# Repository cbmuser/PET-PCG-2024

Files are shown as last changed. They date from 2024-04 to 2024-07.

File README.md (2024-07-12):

# PET-PCG-2024
In the early 80th HAL Laboratory in Japan created a programmable character set generator and sound device for PET/CBM computers. This used the userport and the charater-socket for connection. So it was very easy to use with the first BASIC 1 machines. 
Mike Naberenzy reversed the logic and reassembled the software. A big thanks for that !  
http://mikenaberezny.com/hardware/pet-cbm/hal-pcg-6500-graphics-board/

It's also possible to rebuild the original hardware: https://github.com/InsaneDruid/PCG-6500 for the early BASIC1-machines. There you'll find also other usefull stuff for your PET.

My version fits into the newer dynamic PET-board (CBM 2001/3001) and uses DMA-access at **$a000** or $9000 for transfering the chars. There is no CB2-sound, I want to combine this in the future with a joystick-adapter at the userport.
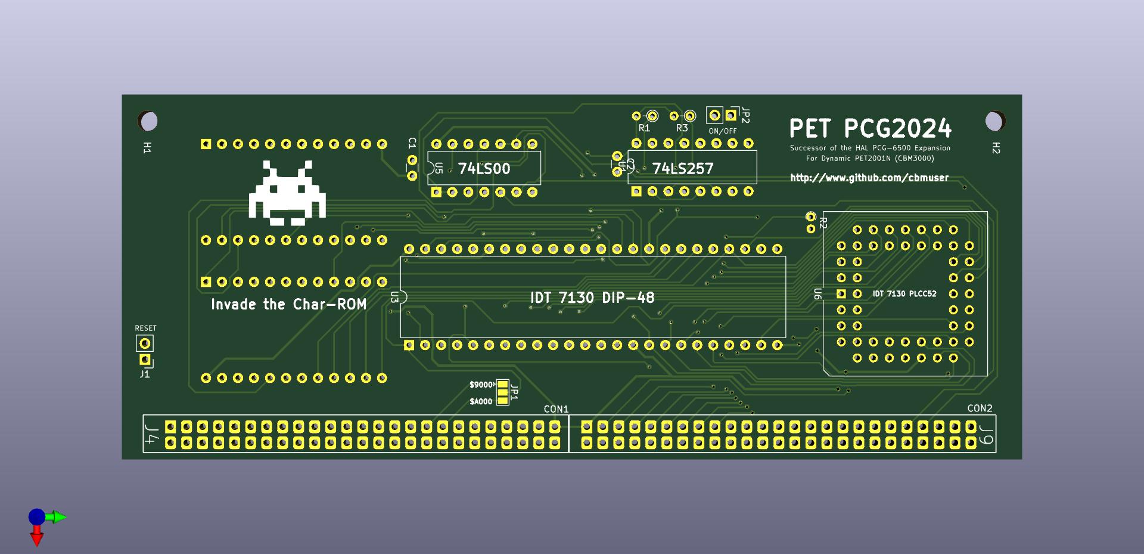
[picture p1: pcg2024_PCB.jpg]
PCB

You can use a IDT7130 in DIP or PLCC52. **You only need one of them !**  
The actual hardware is not tested in all cases (on/off function). Basically it works and new software is under construction, also some games from the HAL-adapter will be patched to this version. The board-routing was done in development-progress, so it works, but it's not the best it can be.  

**This is open hard- and software. Use it on your own risc. There is no warranty at all !**

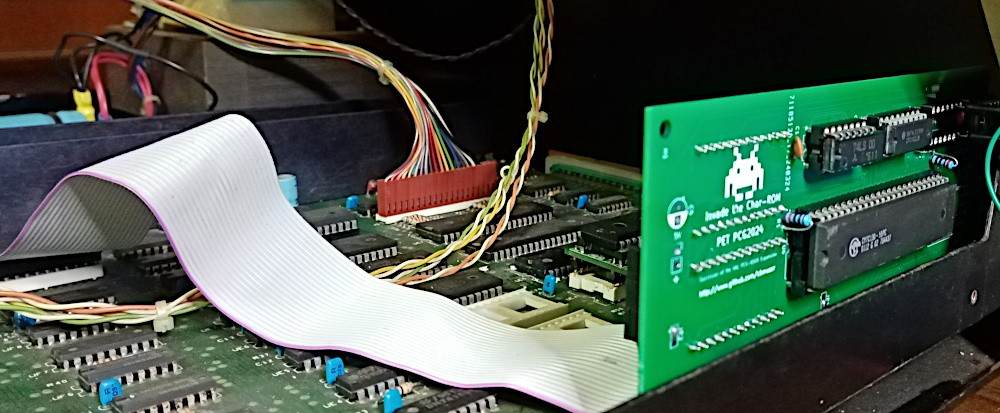
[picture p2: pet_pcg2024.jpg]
development


The first board for development. The first idea was to use banking for addressing the whole ram and the bigger IDT7132. I've kicked this because no one will ever write software for that.

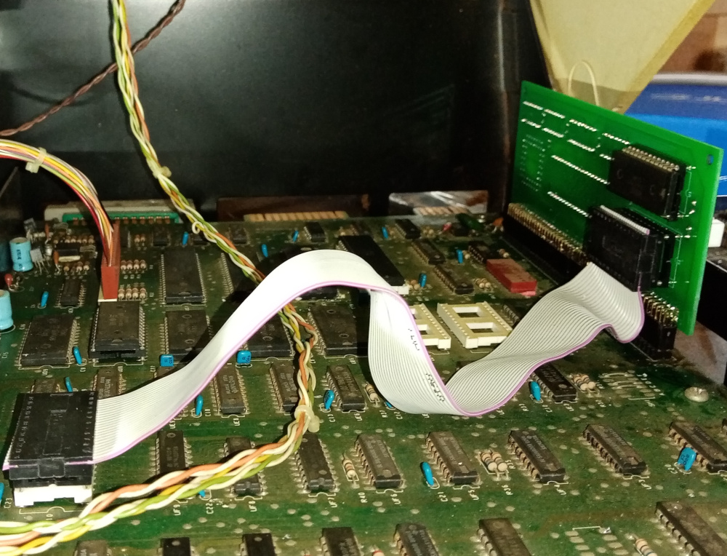
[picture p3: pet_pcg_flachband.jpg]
development1


The char-rom and the connection to the socket fits on the solder-side.

A first character-editor 

charedit

It uses $a000 for the DMA. If you want to compile it for $9000 use the ACME Cross-Assembler. https://sourceforge.net/projects/acme-crossass/

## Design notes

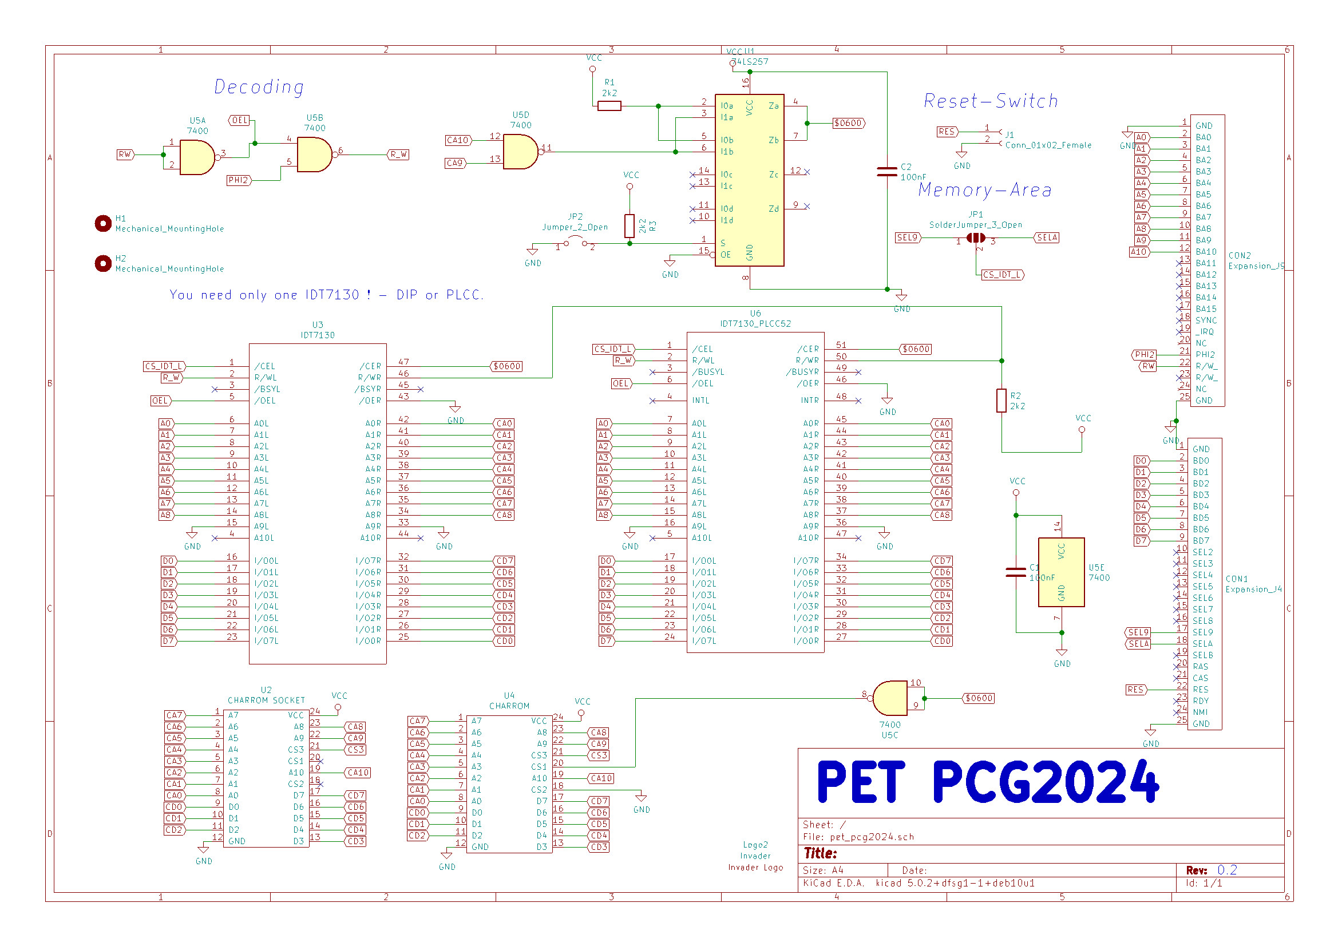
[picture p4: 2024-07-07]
pcg2024_schematic.jpg

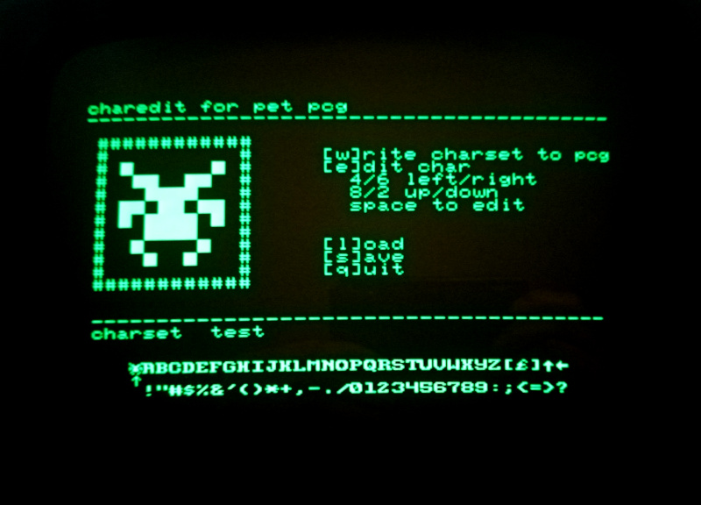
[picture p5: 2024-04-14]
charedit.jpg

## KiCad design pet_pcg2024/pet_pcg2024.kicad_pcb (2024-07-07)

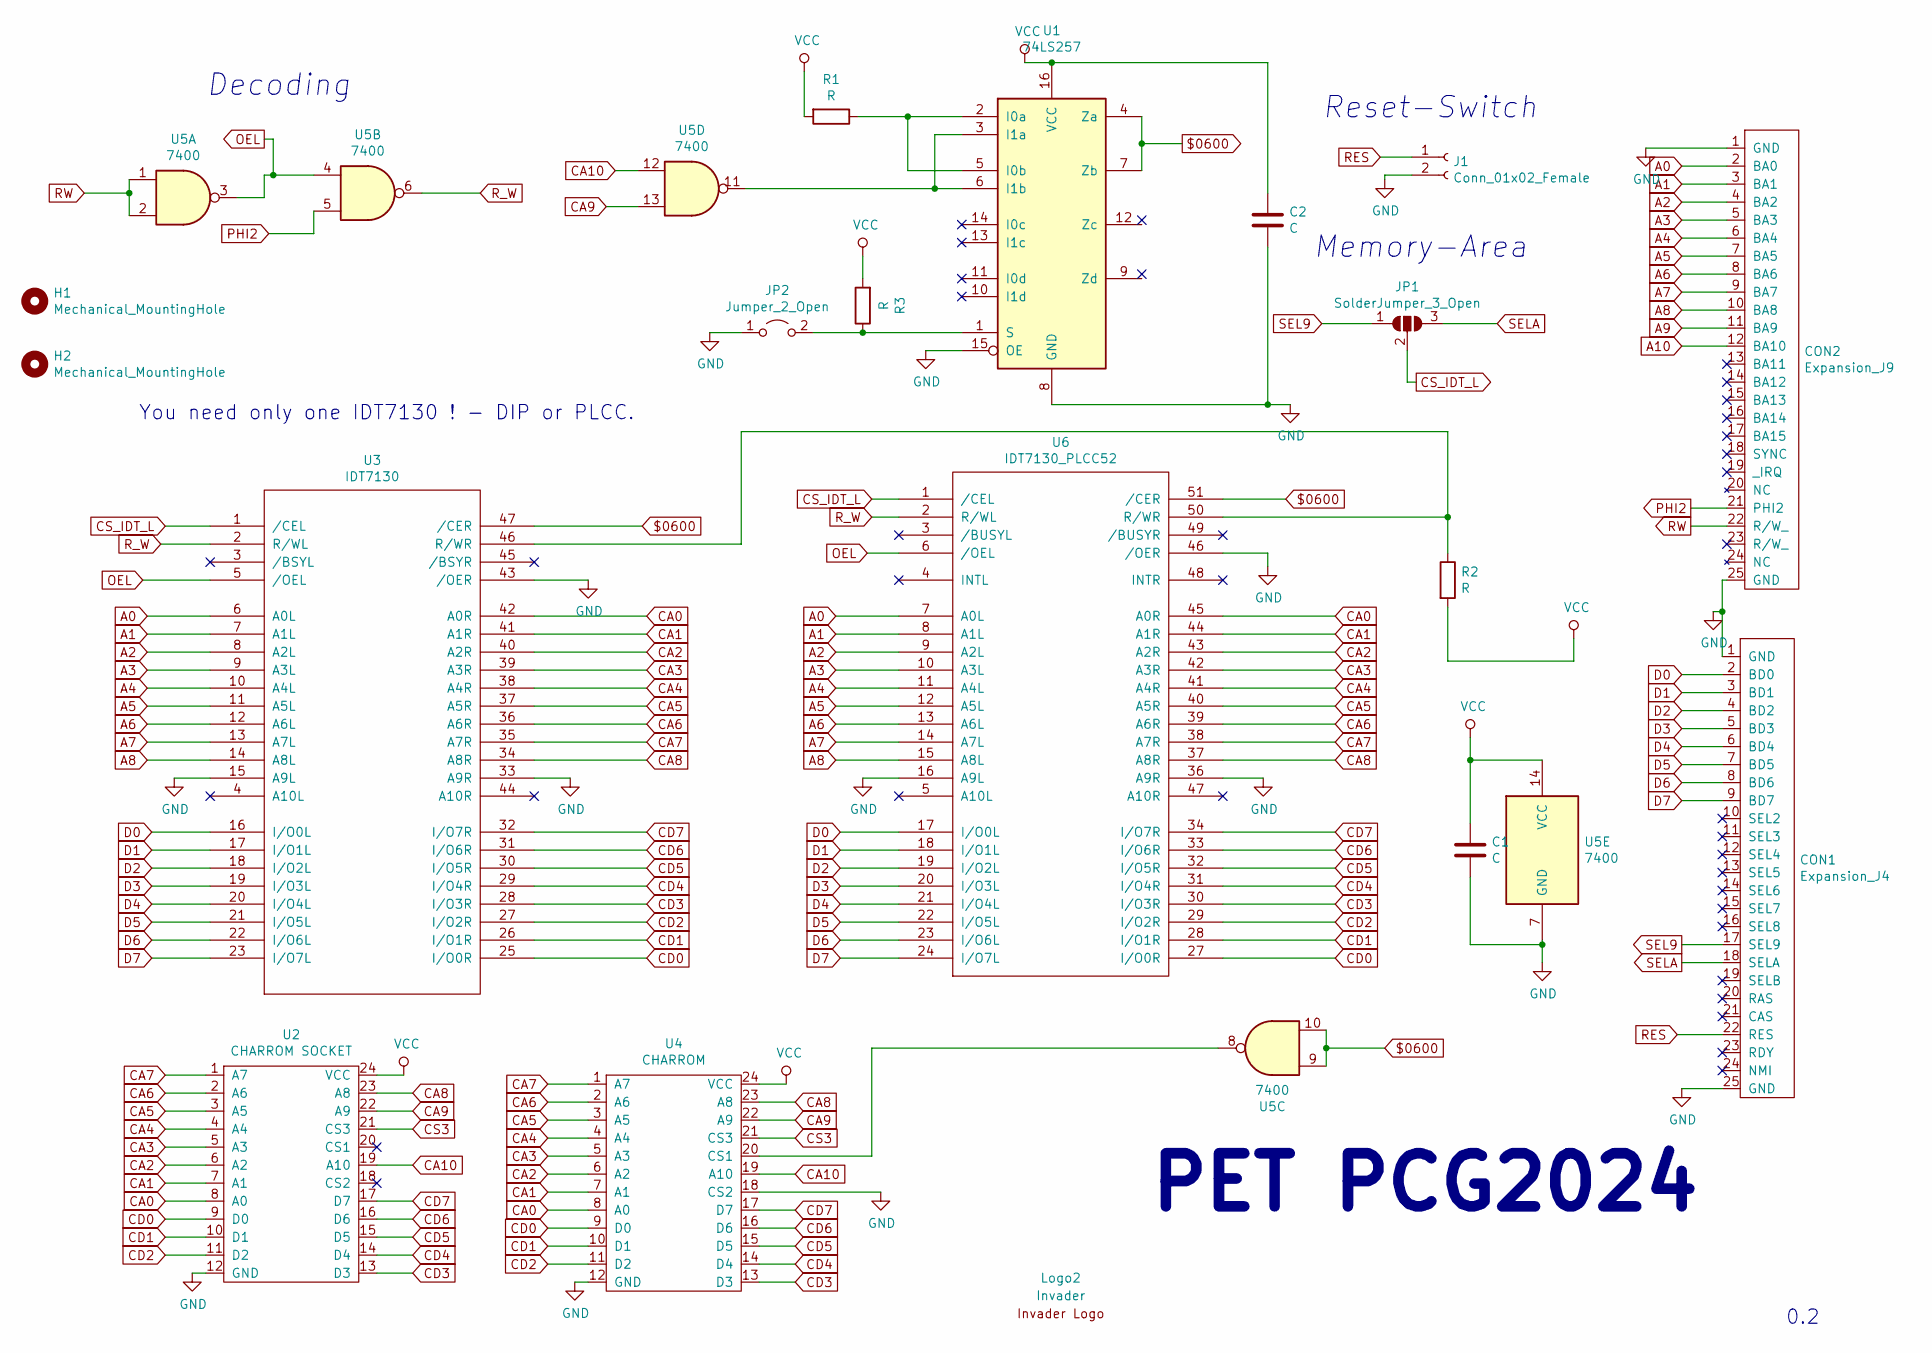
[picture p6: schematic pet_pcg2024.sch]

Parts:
C1, C2: C; C_Disc_D3.0mm_W1.6mm_P2.50mm
CON1: Expansion_J4; PET_EXPANSION_J4
CON2: Expansion_J9; PET_EXPANSION_J9
H1, H2: Mechanical_MountingHole; MountingHole_3.2mm_M3
J1: Conn_01x02_Female; PinHeader_1x02_P2.54mm_Vertical
JP1: SolderJumper_3_Open; SolderJumper-3_P1.3mm_Open_Pad1.0x1.5mm
JP2: Jumper_2_Open; PinHeader_1x02_P2.54mm_Vertical
Logo2: Invader; Invader_klein
R1, R3: R; R_Axial_DIN0204_L3.6mm_D1.6mm_P2.54mm_Vertical
R2: R; R_Axial_DIN0204_L3.6mm_D1.6mm_P1.90mm_Vertical
U1: 74LS257; DIP-16_W7.62mm
U2: CHARROM SOCKET; DIP-24_W15.24mm
U3: IDT7130; DIP-48_W15.24mm
U4: CHARROM; DIP-24_W15.24mm_Socket
U5: 7400; DIP-14_W7.62mm
U6: IDT7130_PLCC52; PLCC-52_THT-Socket

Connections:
$0600: U1.4 (Za), U1.7 (Zb), U3.47 (/CER), U5.9, U5.10, U6.51 (/CER)
A0: CON2.2 (BA0), U3.6 (A0L), U6.7 (A0L)
A1: CON2.3 (BA1), U3.7 (A1L), U6.8 (A1L)
A2: CON2.4 (BA2), U3.8 (A2L), U6.9 (A2L)
A3: CON2.5 (BA3), U3.9 (A3L), U6.10 (A3L)
A4: CON2.6 (BA4), U3.10 (A4L), U6.11 (A4L)
A5: CON2.7 (BA5), U3.11 (A5L), U6.12 (A5L)
A6: CON2.8 (BA6), U3.12 (A6L), U6.13 (A6L)
A7: CON2.9 (BA7), U3.13 (A7L), U6.14 (A7L)
A8: CON2.10 (BA8), U3.14 (A8L), U6.15 (A8L)
A9: CON2.11 (BA9)
A10: CON2.12 (BA10)
CA0: U2.8 (A0), U3.42 (A0R), U4.8 (A0), U6.45 (A0R)
CA1: U2.7 (A1), U3.41 (A1R), U4.7 (A1), U6.44 (A1R)
CA2: U2.6 (A2), U3.40 (A2R), U4.6 (A2), U6.43 (A2R)
CA3: U2.5 (A3), U3.39 (A3R), U4.5 (A3), U6.42 (A3R)
CA4: U2.4 (A4), U3.38 (A4R), U4.4 (A4), U6.41 (A4R)
CA5: U2.3 (A5), U3.37 (A5R), U4.3 (A5), U6.40 (A5R)
CA6: U2.2 (A6), U3.36 (A6R), U4.2 (A6), U6.39 (A6R)
CA7: U2.1 (A7), U3.35 (A7R), U4.1 (A7), U6.38 (A7R)
CA8: U2.23 (A8), U3.34 (A8R), U4.23 (A8), U6.37 (A8R)
CA9: U2.22 (A9), U4.22 (A9), U5.13
CA10: U2.19 (A10), U4.19 (A10), U5.12
CD0: U2.9 (D0), U3.25 (I/O0R), U4.9 (D0), U6.27 (I/O0R)
CD1: U2.10 (D1), U3.26 (I/O1R), U4.10 (D1), U6.28 (I/O1R)
CD2: U2.11 (D2), U3.27 (I/O2R), U4.11 (D2), U6.29 (I/O2R)
CD3: U2.13 (D3), U3.28 (I/O3R), U4.13 (D3), U6.30 (I/O3R)
CD4: U2.14 (D4), U3.29 (I/O4R), U4.14 (D4), U6.31 (I/O4R)
CD5: U2.15 (D5), U3.30 (I/O5R), U4.15 (D5), U6.32 (I/O5R)
CD6: U2.16 (D6), U3.31 (I/O6R), U4.16 (D6), U6.33 (I/O6R)
CD7: U2.17 (D7), U3.32 (I/O7R), U4.17 (D7), U6.34 (I/O7R)
CS3: U2.21 (CS3), U4.21 (CS3)
CS_IDT_L: JP1.2 (C), U3.1 (/CEL), U6.1 (/CEL)
D0: CON1.2 (BD0), U3.16 (I/O0L), U6.17 (I/O0L)
D1: CON1.3 (BD1), U3.17 (I/O1L), U6.18 (I/O1L)
D2: CON1.4 (BD2), U3.18 (I/O2L), U6.19 (I/O2L)
D3: CON1.5 (BD3), U3.19 (I/O3L), U6.20 (I/O3L)
D4: CON1.6 (BD4), U3.20 (I/O4L), U6.21 (I/O4L)
D5: CON1.7 (BD5), U3.21 (I/O5L), U6.22 (I/O5L)
D6: CON1.8 (BD6), U3.22 (I/O6L), U6.23 (I/O6L)
D7: CON1.9 (BD7), U3.23 (I/O7L), U6.24 (I/O7L)
GND: C1.2, C2.2, CON1.1 (GND), CON1.25 (GND), CON2.1 (GND), CON2.25 (GND), J1.2, JP2.1 (A), U1.8 (GND), U1.15 (OE), U2.12 (GND), U3.15 (A9L), U3.24 (GND), U3.33 (A9R), U3.43 (/OER), U4.12 (GND), U4.18 (CS2), U5.7 (GND), U6.16 (A9L), U6.26 (GND), U6.36 (A9R), U6.46 (/OER)
unnamed: JP2.2 (B), R3.1, U1.1 (S)
unnamed: R1.1, U1.2 (I0a), U1.5 (I0b)
unnamed: R2.1, U3.46 (R/WR), U6.50 (R/WR)
unnamed: U1.3 (I1a), U1.6 (I1b), U5.11
unnamed: U4.20 (CS1), U5.8
OEL: U3.5 (/OEL), U5.3, U5.4, U6.6 (/OEL)
PHI2: CON2.21 (PHI2), U5.5
RES: CON1.22 (RES), J1.1
RW: CON2.22 (R/W_), U5.1, U5.2
R_W: U3.2 (R/WL), U5.6, U6.2 (R/WL)
SEL9: CON1.17 (SEL9), JP1.1 (A)
SELA: CON1.18 (SELA), JP1.3 (B)
VCC: C1.1, C2.1, R1.2, R2.2, R3.2, U1.16 (VCC), U2.24 (VCC), U3.48 (VCC), U4.24 (VCC), U5.14 (VCC), U6.52 (VCC)

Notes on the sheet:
PET PCG2024
Reset-Switch
Decoding
Memory-Area
You need only one IDT7130 ! - DIP or PLCC.
0.2

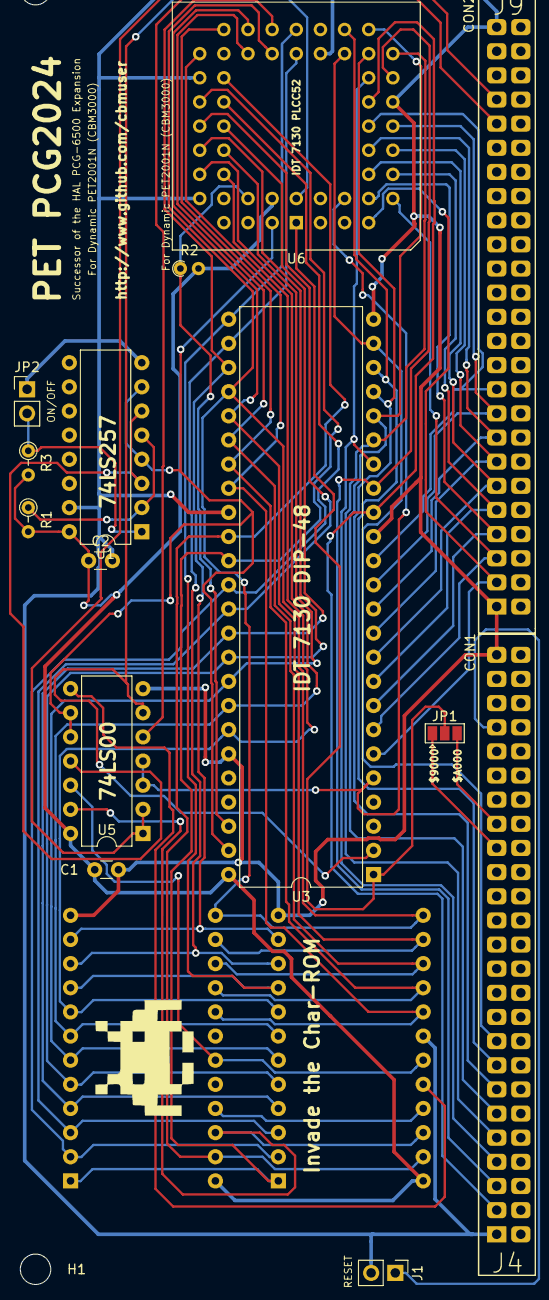
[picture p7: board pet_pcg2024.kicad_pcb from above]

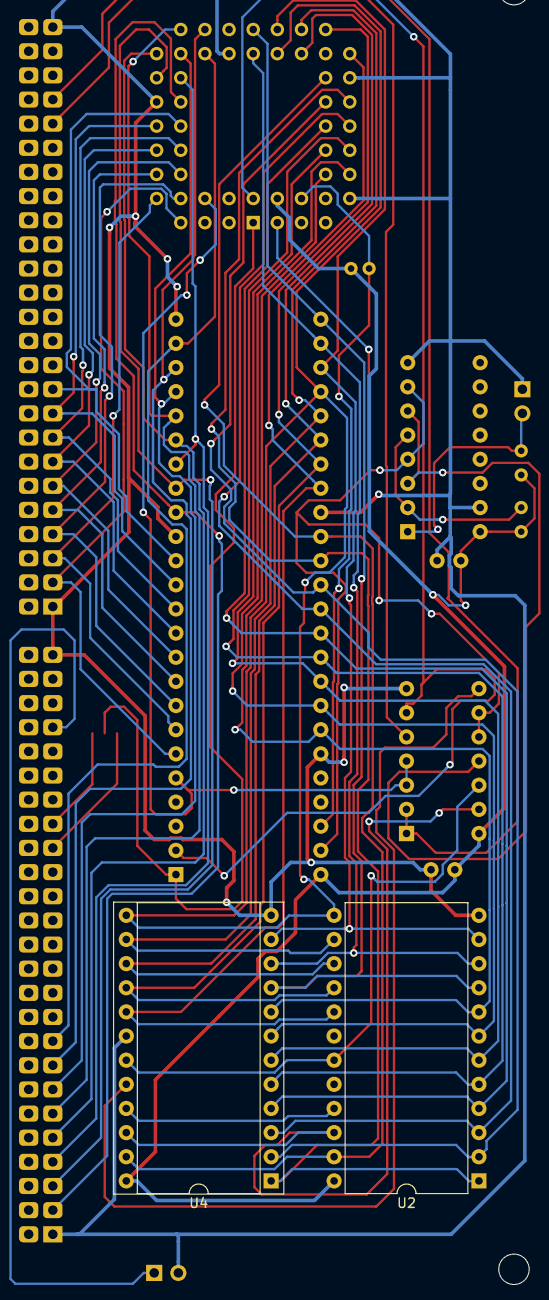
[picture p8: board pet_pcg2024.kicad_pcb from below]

Board: 2 copper layers, 19 parts (2 on the bottom side), 53 nets.

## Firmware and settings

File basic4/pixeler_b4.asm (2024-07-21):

!to"pixeler",cbm
;
; lots of offsets and variables
s_lo         = $0a
s_hi         = $0b
t_lo         = $0c
t_hi         = $0d
temp         = $54
lines        = $55
column       = $56
row          = $57
c_lo         = $58
c_hi         = $59
e_lo         = $5a
e_hi         = $5b
e_column     = $5c
e_row        = $5d
r_lo         = $5e
r_hi         = $5f
; file handling
status       = $96
fnadr        = $da
fnlen        = $d1
la           = $d2 
sa           = $d3 
fa           = $d4
open         = $f563
talk         = $f0d2
listen       = $f0d5
unlisn       = $f1c0
basin        = $ffcf
secnd        = $f2c1
load         = $f356
save         = $f6e3
close        = $f2e0  
; screen and char
char         = $1500
bsout        = $ffd2
*= $0400
!byte $00,$0c,$08,$0a,$00,$9e,$31,$30,$33,$39,$00,$00,$00,$00
; main
*=$040f
          lda #$0e
          sta $e84c 
          lda #$93
          jsr bsout 
          lda #$00
          sta row 
          tay
          tax
          sta t_lo
          lda #$80
          sta t_hi
          lda #<screen
          sta s_lo
          lda #>screen
          sta s_hi
-         lda (s_lo),y
          sta (t_lo),y
          iny
          bne -  
          inc t_hi
          inc s_hi
          inx
          cpx #$03
          bne -     
          ldy #$00
          tya
-         sta $1500,y
          sta $1600,y           
          iny
          bne - 
          lda #<char
          sta s_lo
          lda #>char
          sta s_hi
          lda #$00
          sta t_lo
          lda #$a0
          sta t_hi
          jsr write_charset
          lda #<char
          sta s_lo
          lda #>char
          sta s_hi
          clc  
          lda s_lo
          adc #$08 
          sta s_lo
          bcc +
          inc s_hi 
+         jsr show_charset
          lda #$1e  
          sta $81f1
          lda #$1f  
          sta $80b9
          lda #$00
          sta column 
          lda #$b9
          sta r_lo
          lda #$80
          sta r_hi
          lda #$f1
          sta c_lo
          lda #$81
          sta c_hi
          lda #<char
          sta s_lo
          lda #>char
          sta s_hi
          jsr show_char
          jmp keys

;--------------------------------------------------------------
; update screen
;--------------------------------------------------------------
write_new:
          lda s_lo
          pha
          lda s_hi
          pha
          lda #<char
          sta s_lo
          lda #>char
          sta s_hi
          lda #$00
          sta t_lo
          lda #$a0
          sta t_hi
          jsr write_charset
          pla
          sta s_hi
          pla
          sta s_lo  
          jsr show_charset
          jmp keys 
;--------------------------------------------------------------
; enter filename for load or save 
;--------------------------------------------------------------
new_filename: 
          ldy #$00
          lda #$20
-         sta $82d7,y
          iny
          cpy #$10
          bne - 
          lda #$d7
          sta $c4            ; Pointer: Current Screen	Line Address
          lda #$82
          sta $c5    
          lda #$00
          sta $c6
          lda #$16
          sta $d8 
          lda #<filename 
          sta fnadr   
          lda #>filename 
          sta fnadr+1
          ldy #$00
          sty fnlen     
-         jsr basin
          cmp #$0d           
          beq +
          sta (fnadr),y
          iny
          sty fnlen
          bne -
+         rts         
;--------------------------------------------------------------
; save charset
;--------------------------------------------------------------           
savefile: jsr new_filename
          jsr charset_save
          jmp keys
;--------------------------------------------------------------
; load charset
;--------------------------------------------------------------
loadfile:         
          jsr new_filename
          jsr charset_load 
          lda #<char
          sta s_lo
          lda #>char
          sta s_hi
          lda #$00
          sta t_lo
          lda #$a0
          sta t_hi
          jsr write_charset
          lda #<char
          sta s_lo
          lda #>char
          sta s_hi
          clc  
          lda s_lo
          adc #$08 
          sta s_lo
          bcc +
          inc s_hi 
+         jsr show_charset
          lda column
          tay  
          lda #$20           
          sta (c_lo),y
          ldy #$00 
          sta (r_lo),y
          lda #$1e  
          sta $81f1
          lda #$1f  
          sta $80b9
          lda #$00
          sta column 
          sta row
          lda #$b9
          sta r_lo
          lda #$80
          sta r_hi
          lda #$f1
          sta c_lo
          lda #$81
          sta c_hi
          lda #<char
          sta s_lo
          lda #>char
          sta s_hi
          jsr show_char
          jmp keys
;--------------------------------------------------------------
; keyboard and long jumps
;--------------------------------------------------------------
j_savefile:   jmp savefile 
j_loadfile:   jmp loadfile
j_write_new:  jmp write_new
j_edit_char:  jmp edit_char 
j_move_right: jmp move_right 
j_move_up:    jmp move_up 
j_directory   jmp directory
j_clear       jmp clear
keys:
          jsr $ffe4
          cmp #"6"
          beq j_move_right
          cmp #"4"
          beq move_left
          cmp #"2"
          beq move_down
          cmp #"8"
          beq j_move_up
          cmp #"E"
          beq j_edit_char
          cmp #"W"
          beq j_write_new
          cmp #"C"
          beq j_clear
          cmp #"D"
          beq j_directory
          cmp #"L"
          beq j_loadfile
          cmp #"S"            
          beq j_savefile
          cmp #"Q"
          beq +
          jmp keys
+         lda #$93
          jsr bsout 
          rts
;--------------------------------------------------------------
; move right charlist
;--------------------------------------------------------------
move_right:
          lda column
          cmp #$07
          beq ++
          lda column
          tay 
          lda #$20
          sta (c_lo),y 
          iny
          lda #$1e
          sta (c_lo),y
          sty column         
          clc 
          lda s_lo
          adc #$08           
          sta s_lo
          bcc +
          inc s_hi
+         jsr show_char   
++        jmp keys
;--------------------------------------------------------------
; move left charlist
;--------------------------------------------------------------
move_left:
          lda column
          beq ++
          lda column
          tay 
          lda #$20
          sta (c_lo),y 
          dey
          lda #$1e
          sta (c_lo),y
          sty column            
          sec 
          lda s_lo
          sbc #$08           
          sta s_lo
          bcs +
          dec s_hi
+         jsr show_char   
++        jmp keys
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

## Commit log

2024-07-07 Schematic and board
    [pet_pcg2024.kicad_pcb, pet_pcg2024.sch]
2024-07-07 Update charedit.asm
    small fix
    [charedit.asm]
2024-07-07 Development-Version solder-side
